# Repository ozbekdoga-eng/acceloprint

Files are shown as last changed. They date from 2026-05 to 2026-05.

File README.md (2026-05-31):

# AcceloPrint

AcceloPrint is a customizable accelerometer prototyping project combining multi-material 3D printing, mechanical beam design, capacitive sensing, MATLAB-based modeling, and embedded data-capture workflows.

The project explores how 3D-printed structures can be designed as functional sensing systems, where geometry, material selection, beam length, and fabrication parameters influence the sensing range and response of a printed accelerometer.

The project is published in CHI 2025, LBW session: https://dl.acm.org/doi/10.1145/3706599.3720059

## Repository Structure

```text
matlab/
└── beam_bending_solver/
    ├── MatlabCode_AcceloPRINT.mlx
    └── MatlabCode_AcceloPRINT.pdf

models/
├── blender/
│   └── AcceloPrint_0.2.blend
└── stl/
    ├── Slider.stl
    ├── chasis_0.3.stl
    ├── sm_0.3.stl
    └── se_0.3.stl

cura_profiles/
└── flashforge/
    └── acceloprintmultimaterialprofile-for-flashforge.curaprofile

arduino/
├── sketch_may31c/
│   └── sketch_may31c.ino
└── sketch_may31d/
    └── sketch_may31d.ino
```

## Current Contents

### MATLAB Beam-Bending Solver

The MATLAB workflow implements a reverse solver for estimating cantilever beam dimensions in the AcceloPrint accelerometer structure. It uses material properties, geometric parameters, static loading assumptions, and Euler-Bernoulli beam-bending equations to estimate the cantilever beam length required for a target deflection under a given acceleration input.

### 3D Model Files

The repository includes Blender and STL model files related to the AcceloPrint prototype geometry. These files document the physical design assets used for modeling, fabrication, and iteration.

### Cura Profile

The Cura profile documents multi-material slicing and fabrication settings used for AcceloPrint-related prototyping.

### Arduino Sketches

The Arduino sketches are included as embedded-system code assets for future organization of AcceloPrint data capture, sensor readout, or prototype control workflows.

## Planned Additions

Future additions may include:

- Cleaned and documented Arduino/ESP32 sensor readout code
- Serial data capture scripts
- Calibration and validation workflows
- Example non-private datasets
- Wiring diagrams and setup instructions
- Fabrication and assembly documentation

## Notes

This repository is intended as a project archive and technical portfolio for AcceloPrint. Some parameters may need to be adjusted depending on material properties, printing parameters, infill, geometry, electronics, and experimental validation.

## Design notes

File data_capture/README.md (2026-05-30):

# Data Capture

This folder is reserved for future scripts for serial logging, sensor data capture, and experimental data collection.

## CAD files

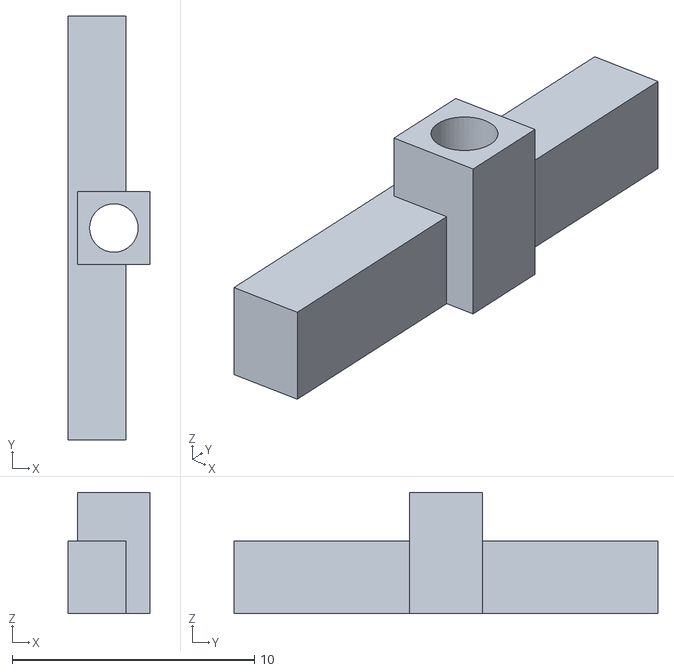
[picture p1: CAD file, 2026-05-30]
models/stl/se_0.3.stl
3.40 x 17.5 x 5.00

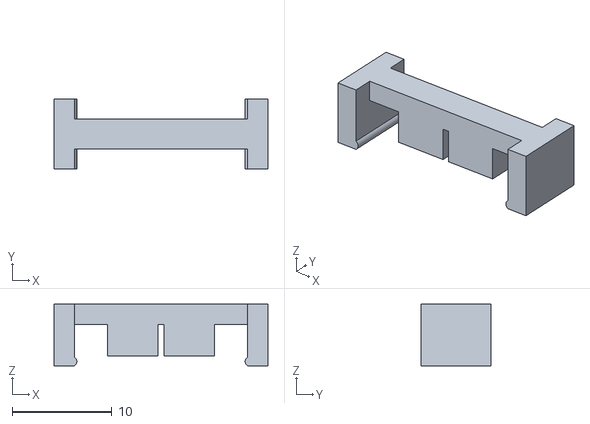
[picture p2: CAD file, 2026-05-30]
models/stl/Slider.stl
21.4 x 7.00 x 6.15

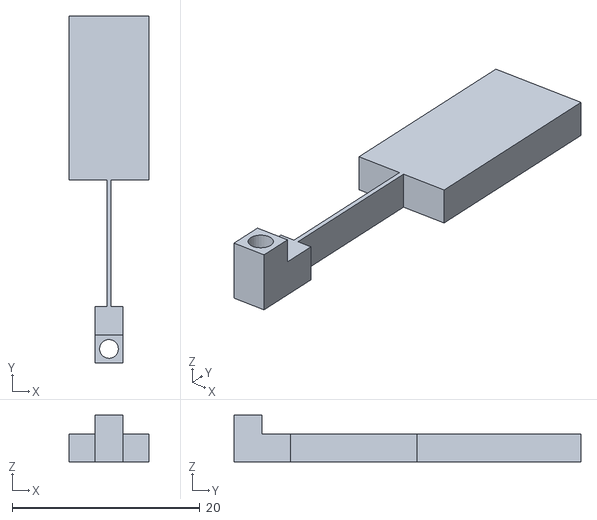
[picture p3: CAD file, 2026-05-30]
models/stl/sm_0.3.stl
8.50 x 37.0 x 5.00

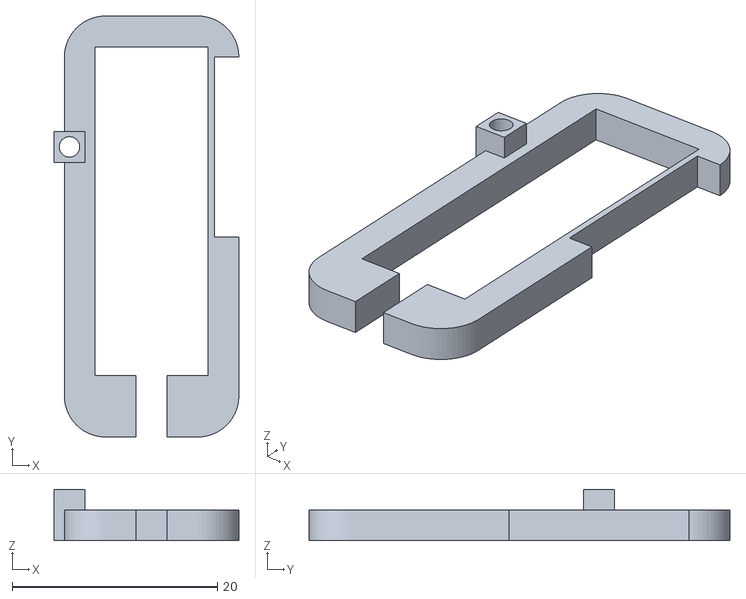
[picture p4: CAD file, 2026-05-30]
models/stl/chasis_0.3.stl
18.0 x 41.0 x 5.00

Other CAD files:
models/blender/AcceloPrint_0.2.blend

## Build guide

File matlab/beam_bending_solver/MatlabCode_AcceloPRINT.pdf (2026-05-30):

## [ACCELOPRINT BEAM BENDING REVERSE SOLVER]

## Set-Up

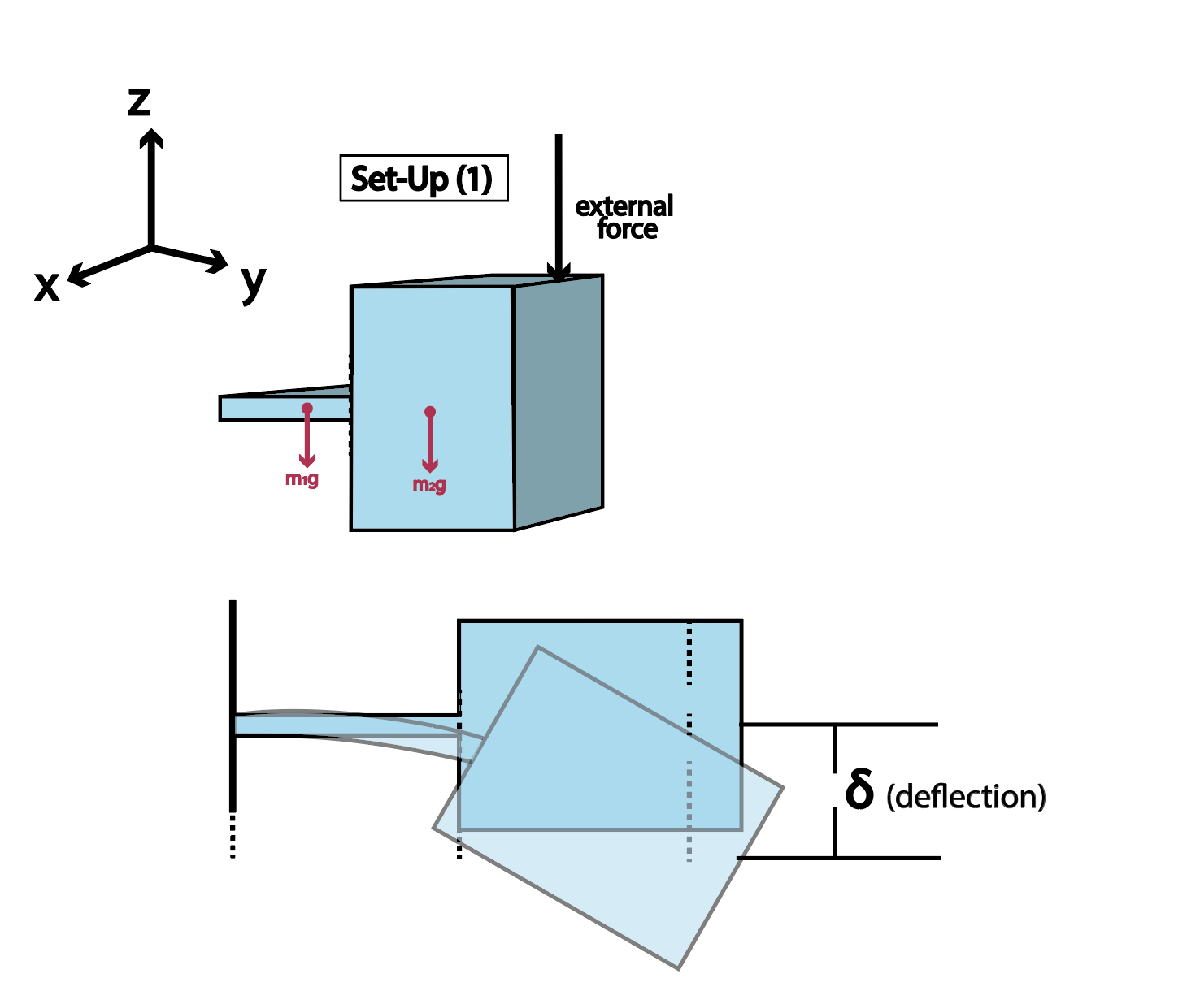
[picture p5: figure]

## Assumptions

1) shearing is negligible of material
2) No plastic deformation/ yield upon loading unloading (though limits must be calculated)

3) E of the material is constant (not true for 3D prints due to anisotropic properties)
4) Density is for prints with 100% infill- otherwise, put a fraction next to density value
5) Static loading

## Goal

1) Amount of Deflection is constant (an INPUT)
2) Another Input is g-force (acceleration)
3) Output is the length of the cantilever beam
4) All other geometrical inputs are constant or fixed

## INPUTS

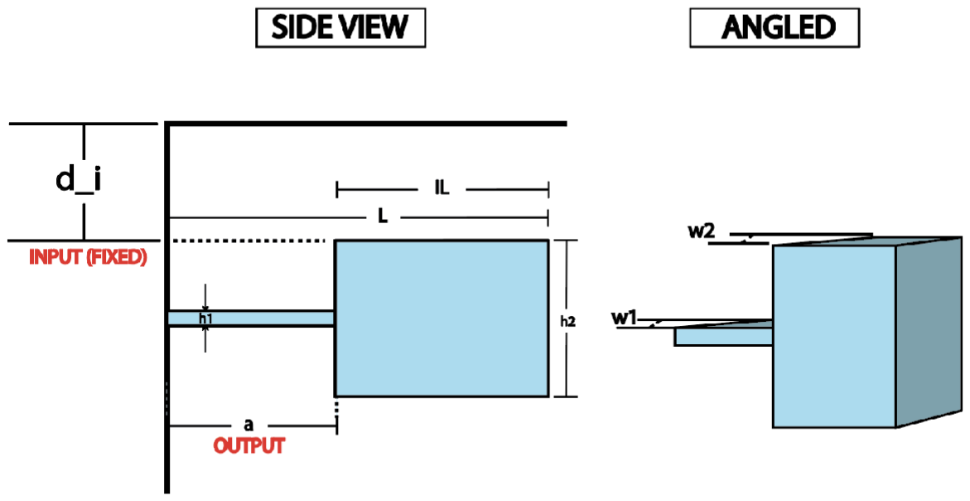
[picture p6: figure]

clear all %clear all previous solutions

## Material properties (TPU and PLA)

E_TPU= 26* 10^6; %Young Modulus (Pascal)
E_PLA= 3250 * 10^6; %Young Modulus (Pascal) -- taken for Ultimaker PLA E_cPLA= 10.7*10^6;

rho_PLA= 1240; %PLA density in Kg/m^3
rho_TPU= 1235; %TPU density in Kg/m^3

E= E_cPLA;
rho= rho_PLA;

## Geometry

%%Lengths [default or Fixed]%%

IL= 17.5 *10^-3; %meters, length of swinging mass

%%Widths [default or Fixed]%%

w1= 0.4*10^-3; %meter, width of the cantilever beam w2= 0.4*10^-3; %meters, width of the swinging mass

%%Heights [default or Fixed]%%

h1= 3*10^-3;%meters, thickness of the cantilever beam. h2= 8.5*10^-3; %meters, thickness of the swinging mass

## Masses (known ONLY)

% Masses %

m2= rho*h2*w2*(IL); %mass of swinging mass

## Acceleration

acc= 10; %m/s^2 %input acceleration or"g-force"
g= 9.81; %m/s^2 "gravitational acceleration constant"

## Deflection

%%deflection [default or Fixed]%%

d_i= 1.25 *10^-3; %meters, distance from the swinging mass's end to the frame of Acceloprint Deflection_endmass= d_i+h2/2; %meters, deflection from neutral axis (the one we get from solving equations with)

## Moment of Inertias

I1= MomentInertia(w1, h1); %moment of inertia of cantilever beam
I2= MomentInertia(w2, h2); %moment of inertia swinging mass

## Equations for reaction forces and moments

Since this is a cantilever beam problem, the Free body diagram (with reaction forces) looks like the picture below. There are both reaction moments and reaction forces at the position (y=0). Which we calculate and find expressions for in this section.

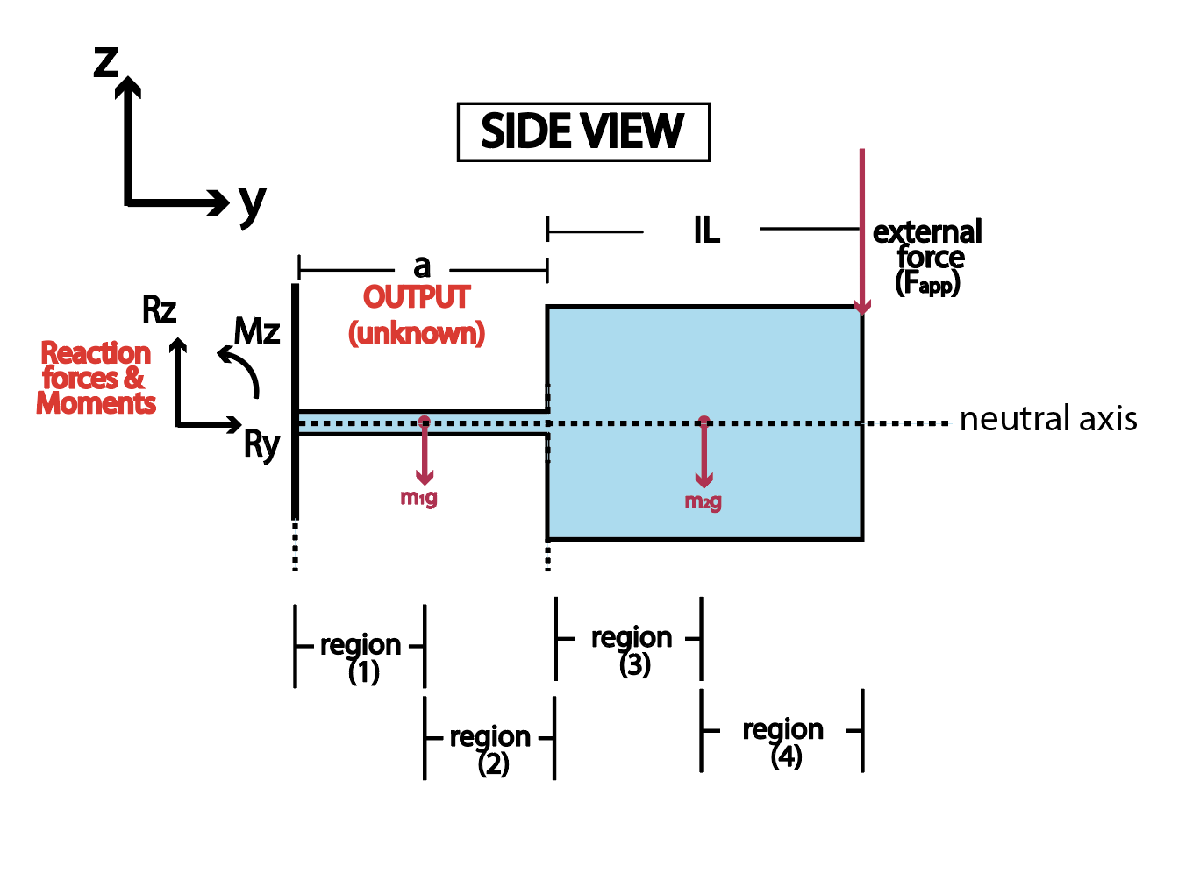
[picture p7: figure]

How we solve is based on static loading condition assumption (F_total=0, M_total=0)

%z loading reaction force %
syms a y
m1= rho*h1*w1*a; %mass of the cantilever rod (without the end mass)
Fapp= (m1+m2)*acc; %applied force at the end mass
Rz(a)= m1*g+ m2*g + Fapp; %reaction force at the fixed end of the cantilever (y=0)
MR(a)= (m1*g*a/2)+ m2*g*(a+IL/2)+Fapp*(a+IL); %reaction moment at the fixed end of the cantilever (y=0)

## Region (1) -- (region from 0<y<a/2)--

## Prior to the center of mass force on cantilever beam

We solve here for deflection at end of region (1) which is used as end condition for region (2)

v_1= Rz(a); %force at y
Mz_1(y)= y*v_1-MR(a); %moment at y

%We next double integrate to get the deflection in region(1)%%

C1_r1= 0 ; %initial condition for slope
C2_r1= 0; %initial condition for deflection

fr1(y)= Mz_1(y)/(E*I1); %Euler-Bernouille Equation Left-hand-side equation
slope_r1 (y)= int(fr1,y) +C1_r1; %First integration of Euler-Bernouilli

deflection_r1(y)= int(slope_r1,y) +C2_r1;%Second integration of Euler-Bernouilli to get deflection

## Region (2) -- (region from a/2<y<a) --

## ie, After the center of mass force on cantilever beam AND before the change in cross section (ie from cantilever beam to swinging mass)

We solve here for deflection at end of region (2) which is used as end condition for region (3)

C1_r2= slope_r1 (a/2); %initial condition for slope at a/2
C2_r2= deflection_r1(a/2); %initial condition for deflection at a/2

v_2= Rz(a)-m1*g; %force at y
Mz_2(y)= v_2*y+m1*g*(a/2)-MR(a); %moment at y

fr2(y)= Mz_2(y)/(E*I1); %Euler-Bernouille Equation Left-hand-side equation slope_r2(y)= int(fr2,y) +C1_r2; %First integration of Euler-Bernouilli

deflection_r2(y)= int(slope_r2,y) +C2_r2;%Second integration of Euler-Bernouilli

## Region (3) -- (region from a<y<a+IL/2)

## Prior to the center of mass force on the swinging mass

We solve here for deflection at end of region (3) which is used as end condition for region (4)

C1_r3= slope_r2 (a); %initial condition for slope at a
C2_r3= deflection_r2(a); %initial condition for deflection at a

v_3= Rz(a)-m1*g; %force at y
Mz_3(y)= v_3*y+m1*g*(a/2)-MR(a); %moment at y

fr3(y)= Mz_3(y)/(E*I2); %Euler-Bernouille Equation Left-hand-side equation slope_r3 (y)= int(fr3,y) +C1_r3; %First integration of Euler-Bernouilli deflection_r3(y)= int(slope_r3,y) +C2_r3; %Second integration of Euler-Bernouilli

## Region (4) -- (region from a+IL/2<y<a+IL)

C1_r4= slope_r3 (a+ IL/2); %initial condition for slope at a+IL/2
C2_r4= deflection_r3(a + IL/2); %initial condition for deflection at a+IL/2

v_4= Rz(a)-m1*g-m2*g; %force at y
Mz_4(y)= v_4*y+m1*g*(a/2)+m2*g*(a+IL/2)-MR(a); %moment at y

fr4(y)= Mz_4(y)/(E*I2); %Euler-Bernouille Equation Left-hand-side equation
slope_r4 (y)= int(fr4,y) +C1_r4; %First integration of Euler-Bernouilli

deflection_r4(y)= simplify(int(slope_r4,y) +C2_r4); %Second integration of Euler-Bernouilli

SOLUTION: Solve for a with deflection at end--;

C= deflection_r4(a); %set up equation of deflection at end of swinging mass to be in terms of "a"

%SOLUTION VISUALLY%
fplot(-C,[0,0.05]) %plot the function of deflection at the end of swinging mass with range of a values from 0 to 5cm yline(Deflection_endmass); %plot the solution line for deflection beased on input

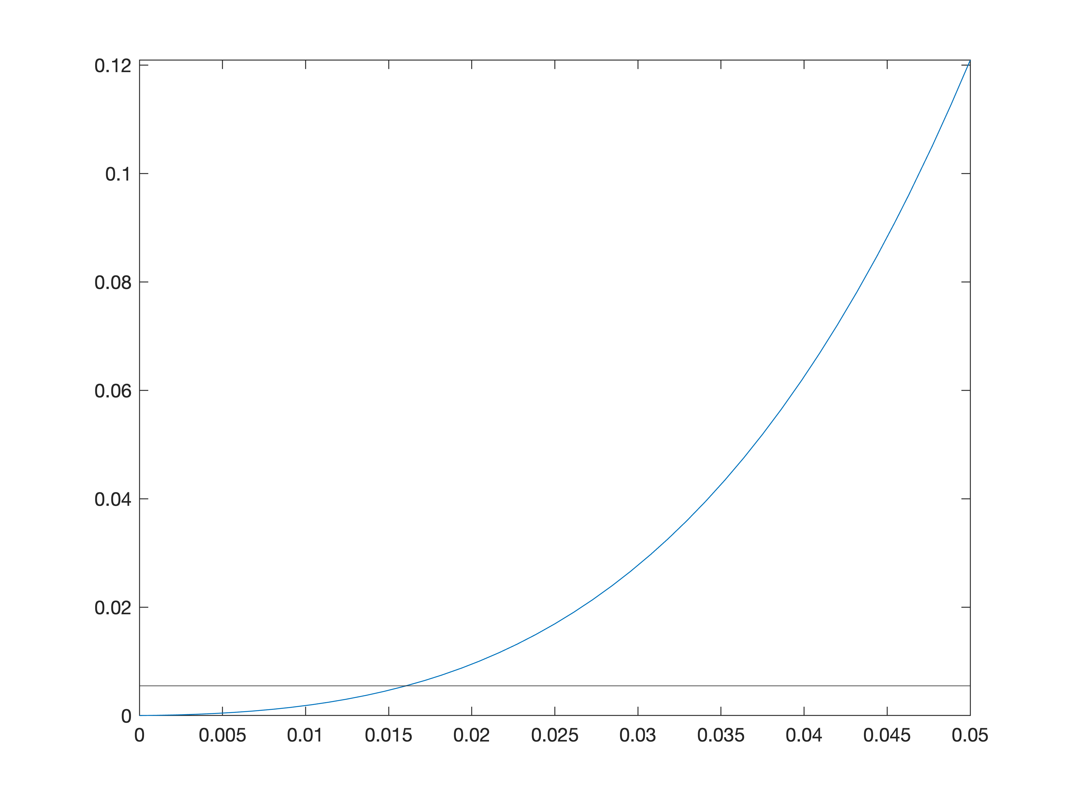
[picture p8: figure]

%SOLUTION NUMERICALLY- BASED ON SOLVING EQUATION%
solx = vpasolve(-1*C == Deflection_endmass, a); %solution to equation of deflection at end of swinging mass wrt a, where a is the cantilever beam length solution= solx( solx>=0 ) %only accept positive values for a (ie the cantilever beam length)

solution =

%convert to milimeters
solution_mm= solution*10^3

solution_mm =

## Moment of inertia Equation

Function to compute the moment of inertia of a rectangular beam (about the neutral axis)

function I = MomentInertia(w, h)
I= (1/12)*w*(h)^3;

end

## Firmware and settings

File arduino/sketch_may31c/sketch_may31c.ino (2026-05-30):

#include <esp_now.h>
#include <WiFi.h>

#include <Adafruit_MCP3008.h> // Communication with ADC
#include <Adafruit_MPU6050.h> // Communication with MPU
#include <Adafruit_Sensor.h> // Communication with MPU
#include <Wire.h> // Communication with MPU

#include <SimpleKalmanFilter.h>

SimpleKalmanFilter simpleKalmanFilter(2, 2, 0.01);

/* MPU global */
Adafruit_MPU6050 mpu;
/*MPU global END*/
/* ADC global */
Adafruit_MCP3008 adc;

float maxFilter_NumMaxRead = 10; // Number for which the maximum value is updated

int maxChannel0Value = 0;  // Variable to store the maximum value by channel 0
unsigned long startTime;
unsigned long printTime;
unsigned long updateTime;


// REPLACE WITH YOUR RECEIVER MAC Address
uint8_t broadcastAddress[] = {0x10, 0xAA, 0xBB, 0xCC, 0x33, 0xF5};

// Structure example to send data
// Must match the receiver structure
typedef struct struct_message {
  float sensor1;
  float sensor2;
  float sensor3;
  float sensor4;
  float sensor5;
} struct_message;

// Create a struct_message called myData
struct_message myData;

esp_now_peer_info_t peerInfo;

// callback when data is sent
void OnDataSent(const uint8_t *mac_addr, esp_now_send_status_t status) {
  Serial.print("\r\nLast Packet Send Status:\t");
  Serial.println(status == ESP_NOW_SEND_SUCCESS ? "Delivery Success" : "Delivery Fail");
}
 
void setup() {
  // Init Serial Monitor
  Serial.begin(115200);

  adc.begin(14, 13, 12, 25);

    printTime = 0;
    updateTime = 0;
  /* END INIT ADC*/

  /*Init for MPU*/
    while (!Serial)
      delay(10); // will pause Zero, Leonardo, etc until serial console opens

    Serial.println("Adafruit MPU6050 test!");

    // Try to initialize!
    if (!mpu.begin()) {
      Serial.println("Failed to find MPU6050 chip");
      //while (1) {
      //  delay(10);
      //}
    }
    Serial.println("MPU6050 Found!");

    mpu.setAccelerometerRange(MPU6050_RANGE_8_G);
    Serial.print("Accelerometer range set to: ");
    switch (mpu.getAccelerometerRange()) {
    case MPU6050_RANGE_2_G:
      Serial.println("+-2G");
      break;
    case MPU6050_RANGE_4_G:
      Serial.println("+-4G");
      break;
    case MPU6050_RANGE_8_G:
      Serial.println("+-8G");
      break;
    case MPU6050_RANGE_16_G:
      Serial.println("+-16G");
      break;
    }
    mpu.setGyroRange(MPU6050_RANGE_500_DEG);
    Serial.print("Gyro range set to: ");
    switch (mpu.getGyroRange()) {
    case MPU6050_RANGE_250_DEG:
      Serial.println("+- 250 deg/s");
      break;
    case MPU6050_RANGE_500_DEG:
      Serial.println("+- 500 deg/s");
      break;
    case MPU6050_RANGE_1000_DEG:
      Serial.println("+- 1000 deg/s");
      break;
    case MPU6050_RANGE_2000_DEG:
      Serial.println("+- 2000 deg/s");
      break;
    }

    mpu.setFilterBandwidth(MPU6050_BAND_5_HZ);
    Serial.print("Filter bandwidth set to: ");
    switch (mpu.getFilterBandwidth()) {
    case MPU6050_BAND_260_HZ:
      Serial.println("260 Hz");
      break;
    case MPU6050_BAND_184_HZ:
      Serial.println("184 Hz");
      break;
    case MPU6050_BAND_94_HZ:
      Serial.println("94 Hz");
      break;
    case MPU6050_BAND_44_HZ:
      Serial.println("44 Hz");
      break;
    case MPU6050_BAND_21_HZ:
      Serial.println("21 Hz");
      break;
    case MPU6050_BAND_10_HZ:
      Serial.println("10 Hz");
      break;
    case MPU6050_BAND_5_HZ:
      Serial.println("5 Hz");
      break;
    }

    Serial.println("");
    delay(100);
  /* END INIT MPU*/
 
  // Set device as a Wi-Fi Station
  WiFi.mode(WIFI_STA);

  // Init ESP-NOW
  if (esp_now_init() != ESP_OK) {
    Serial.println("Error initializing ESP-NOW");
    return;
  }

  // Once ESPNow is successfully Init, we will register for Send CB to
  // get the status of Transmitted packet
  esp_now_register_send_cb(OnDataSent);
  
  // Register peer
  memcpy(peerInfo.peer_addr, broadcastAddress, 6);
  peerInfo.channel = 0;  
  peerInfo.encrypt = false;
  
  // Add peer        
  if (esp_now_add_peer(&peerInfo) != ESP_OK){
    Serial.println("Failed to add peer");
    return;
  }
}
 
void loop() {

  /*ADC Reading*/
    // Reset the max value for each iteration
    maxChannel0Value = 0;

    // Record the start time
    startTime = millis();

    
    //Max Filtering:
      // Capture readings for maxFilter_time
  while (millis() - startTime < 0.1) {
    updateMaxValues();
  }
 
  if (millis() - updateTime >= 5) {
    updateTime = millis();
    float estimated_value = simpleKalmanFilter.updateEstimate(maxChannel0Value);
  
  /* MPU Reading */
    /* Get new sensor events with the readings */
    sensors_event_t a, g, temp;
    mpu.getEvent(&a, &g, &temp);
  /* MPU Reading END*/

    myData.sensor1 = a.acceleration.x;
    myData.sensor2 = a.acceleration.y; // in m/s2
    myData.sensor3 = a.acceleration.z; // in m/s2
    myData.sensor4=estimated_value;
    myData.sensor5=maxChannel0Value;
  }

  /* Print the values after a 5ms window*/
    if (millis() - printTime >= 10) {
      printTime = millis();
      // Send message via ESP-NOW
      esp_err_t result = esp_now_send(broadcastAddress, (uint8_t *) &myData, sizeof(myData));
      
      if (result == ESP_OK) {
        Serial.println("Sent with success");
      }
      else {
        Serial.println("Error sending the data");
      }      
    }

  

}

void updateMaxValues() {
  int channel0Value = adc.readADC(0);

  if (channel0Value > maxChannel0Value) {
    maxChannel0Value = channel0Value;
  }
}

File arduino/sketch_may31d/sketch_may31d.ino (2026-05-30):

#include <esp_now.h>
#include <WiFi.h>
#include <esp_wifi.h>

uint8_t New_MAC_Address[] = {0x10, 0xAA, 0xBB, 0xCC, 0x33, 0xF5};

// Structure example to receive data
// Must match the sender structure
typedef struct struct_message {
  float sensor1;
  float sensor2;
  float sensor3;
  float sensor4;
  float sensor5;
} struct_message;

struct_message incomingData;

// Callback when data is received
void OnDataRecv(const esp_now_recv_info_t *recv_info, const uint8_t *data, int len) {
  // Copy the received data into the incomingData structure
  memcpy(&incomingData, data, sizeof(incomingData));

  // Print the received sensor readings
  Serial.print(incomingData.sensor4);
  Serial.print("\t");
  Serial.print(incomingData.sensor2);
  Serial.print("\t");
  Serial.print(incomingData.sensor3);
  Serial.print("\t");
  Serial.print(incomingData.sensor1);
  Serial.print("\t");
  Serial.print(incomingData.sensor5);
  Serial.print("\t");
  Serial.print(28.5);
  Serial.println();
}


void setup() {
  // Init Serial Monitor
  Serial.begin(115200);
 
  // Set device as a Wi-Fi Station
  WiFi.mode(WIFI_STA);
  esp_wifi_set_mac(WIFI_IF_STA, New_MAC_Address);

  // Init ESP-NOW
  if (esp_now_init() != ESP_OK) {
    Serial.println("Error initializing ESP-NOW");
    return;
  }

  // Register callback for receiving data
  esp_now_register_recv_cb(OnDataRecv);
}

void loop() {
  // Do nothing in the loop, data is received in the callback function
}

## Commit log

2026-05-30 Initial commit: AcceloPrint project files
    [AcceloPrint_0.2.blend, Slider.stl, chasis_0.3.stl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]
2026-05-31 Update README to remove outdated sections
    Removed sections for data_capture, calibration, docs, and examples.
